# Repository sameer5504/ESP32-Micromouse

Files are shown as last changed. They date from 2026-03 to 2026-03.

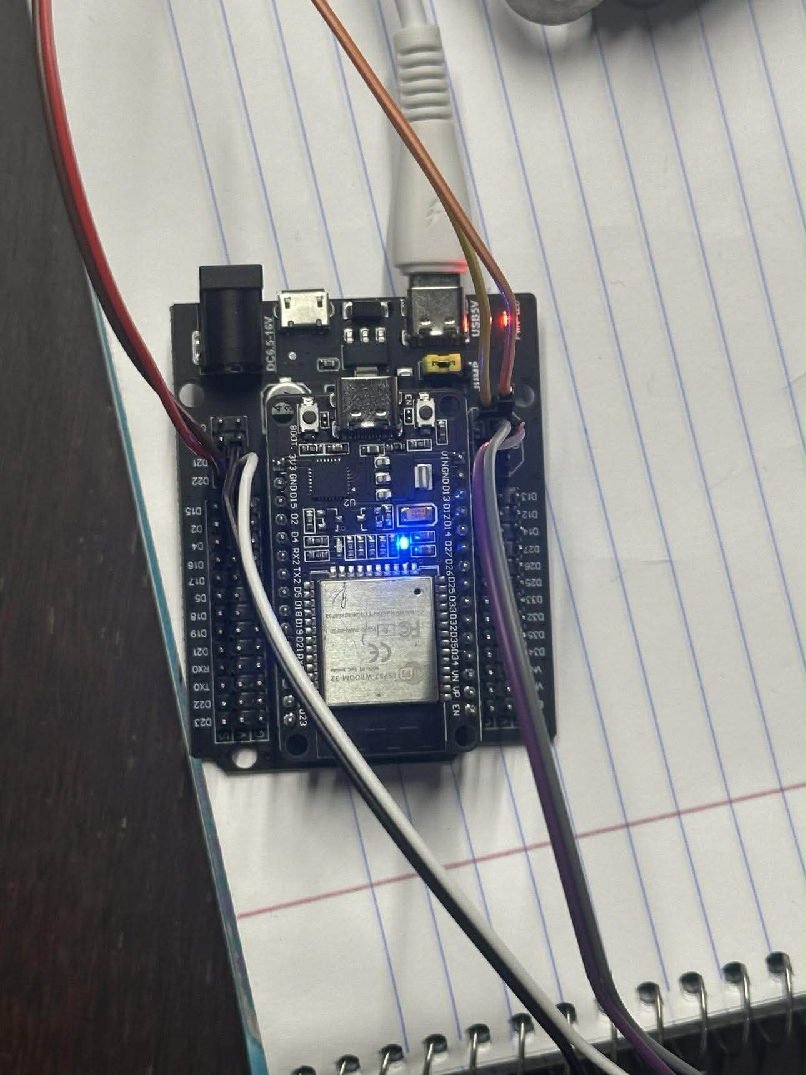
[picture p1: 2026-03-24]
ESP32 Sensor testing.jpg

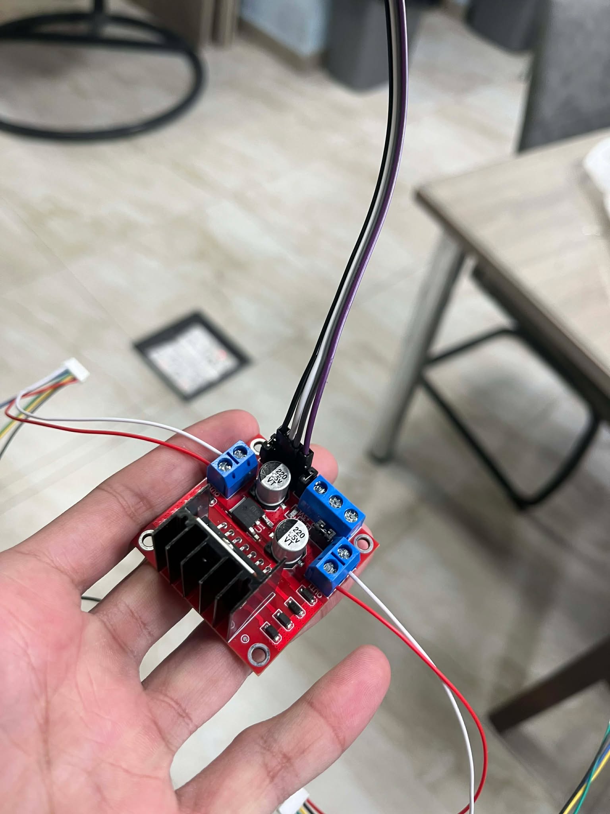
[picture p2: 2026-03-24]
L928N - H bridge.jpg

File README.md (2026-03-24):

# 🐭 ESP32 Micromouse – Flood Fill Maze Solver

## 📌 Overview

This project implements a **Micromouse robot** using an ESP32 microcontroller that autonomously navigates and solves a maze using the **Flood Fill algorithm**.

The robot explores the maze using sensors, builds a map in real time, computes the shortest path to the center, and optimizes its route over multiple runs.

---

## ⚙️ Hardware Components

* ESP32 Microcontroller
* ESP32 30-pin Expansion Board (Shield)
* MPU6050 (Gyroscope + Accelerometer)
* DC Motors with Encoders ×2
* L298N (L928N) H-Bridge Motor Driver
* VL53L0X LiDAR Sensors ×2 (Left & Right)
* IR Sensor (Front wall detection)
* Caster Balls ×2

---

## 🔌 Pin Configuration

| Component | ESP32 Pin |
| --- | --- |
| Motor IN1 | 25 |
| Motor IN2 | 26 |
| Motor IN3 | 27 |
| Motor IN4 | 14 |
| Left Encoder  | 32 |
| Right Encoder | 4 |
| LiDAR XSHUT 1 | 17 |
| LiDAR XSHUT 2 | 18 |
| IR Sensor | 19 |
| I2C SDA | 21 |
| I2C SCL | 22 |

---

## 🧠 Algorithm

### Flood Fill Algorithm

* The maze is represented as an **8×8 grid**
* Each cell stores:

  * Walls (N, E, S, W)
  * Cost (distance to goal)
* The robot:

  1. Explores the maze using sensors
  2. Updates walls dynamically
  3. Recomputes shortest paths using **BFS (Flood Fill)**
  4. Moves toward the lowest-cost neighbor

---

## 🤖 Robot Behavior

### Exploration Phase

* Uses:

  * IR sensor → front wall
  * LiDAR → left/right walls
* Updates maze map in real-time
* Recomputes path continuously

### Optimization Phase

* Once the optimal path is stable:

  * Stops using sensors
  * Runs fastest path

---

## ⚡ Motion Control

* **Yaw correction** using MPU6050
* **PID-like control** for:

  * Straight movement
  * Precise turning
* Encoder-based distance tracking

---

## 📏 Key Parameters

* Wheel diameter: 46 mm
* Cell size: 190 mm
* Encoder resolution: 203 ticks/rev
* Base speed: 50 PWM
* Turn tolerance: ±0.5°

---

## 📂 Code Structure

* **Motor Control** → PWM + direction logic
* **Sensors API** → IR + LiDAR readings
* **IMU Handling** → angle tracking & calibration
* **Flood Fill** → BFS-based pathfinding
* **Stack/Queue** → path tracking & backtracking

---

## 🚀 How It Works

1. Robot starts at (0,0)
2. Moves forward while sensing walls
3. Updates internal maze representation
4. Runs Flood Fill to compute shortest path
5. Reaches center goal
6. Returns to start
7. Repeats until optimal path is found

---

## 📸 Demo

*(Add your video or images here)*

---

## 🛠️ How to Run

1. Open project in Arduino IDE / PlatformIO
2. Install required libraries:

   * Adafruit MPU6050
   * Adafruit VL53L0X
3. Upload code to ESP32
4. Place robot in maze and power on

---

## 📈 Future Improvements

* Faster path optimization
* Better PID tuning
* Diagonal movement
* Map visualization interface

---

## 👨‍💻 Author

**Sameer**
Computer Engineering Student

---

## ⭐ Notes

This project combines:

* Embedded Systems
* Robotics
* Algorithms (Flood Fill / BFS)
* Real-time control

---

> Built as part of a Micromouse robotics project using ESP32 🚀

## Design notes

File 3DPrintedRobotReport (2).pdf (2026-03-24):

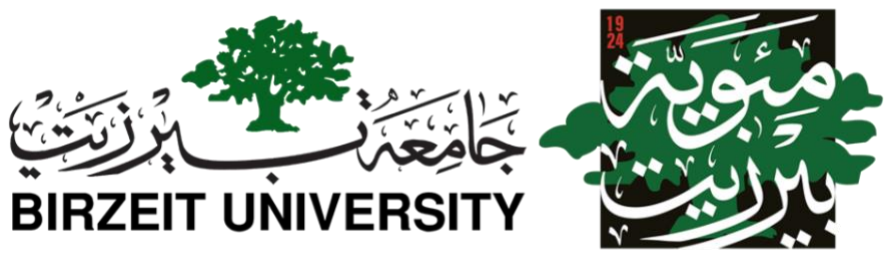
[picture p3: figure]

### Faculty of Engineering & Technology

### Department of Computer Science

### INTERFACING TECHNIQUES ‐ ENCS 4380

### First Semester - 2025/2026

### 3D Printing Homework

Prepared by:

Samir Ali | 1222350
Ibrahim Al Ardah | 1220874
Maen Foqaha | 1220847
Mohammad Ewais | 1220053

Sec. 1 & 2

Instructor: Dr. Wasel Ghanem

Date: 25.10.2025

## Design Objectives

The main objective of this 3D design was to create a compact, lightweight, and durable chassis for a Micromouse robot that could be easily fabricated using 3D printing. The design focuses on achieving a strong structural framework that maintains balance, accessibility, and a clean aesthetic suitable for competition use.

The chassis was developed with the following key goals:

- Ease of Fabrication: Ensure that the entire body can be efficiently produced using standard 3D printing materials with minimal support structures.
- Structural Strength and Stability: Provide a rigid frame capable of withstanding vibrations and small impacts while supporting essential components including motors, sensors, and the battery pack.
- Compact and Balanced Layout: Maintain a symmetrical and low profile design to achieve even weight distribution, enhancing maneuverability and stability during maze navigation.
- Accessibility and Modularity: Integrate mounting holes, open sections, and layered plates that allow easy assembly, disassembly, and maintenance of the robot’s components.
- Aesthetic and Functional Design: Combine clean, modern geometry with smooth edges and cutouts that not only reduce weight but also contribute to a professional and visually appealing appearance.

## Design Approach

The design approach for this Micromouse chassis centered around creating a simple, rigid, and easily manufacturable 3D printed structure that balances practicality, strength, and visual appeal. The robot body was designed with a two-layer configuration connected by sensor-holding side supports, forming a compact and stable frame to hold all main components such as the motors, sensors, control board, and battery pack.

The lower plate is the foundation of the robot, supporting the front mounted sensors and wheels while maintaining sufficient ground clearance to avoid friction during movement. The upper plate provides a mounting space for the battery and microcontroller, keeping heavier components closer to the center to achieve a low and balanced center of gravity essential for accurate and stable navigation within a maze environment. The side walls add rigidity to the chassis while also serving as sensor holders.

From a fabrication standpoint, the design was optimized for 3D printing. The geometry was simplified to include smooth contours, uniform wall thickness, and minimal overhangs, allowing the model to print without the need for excessive support. Mounting holes and slots were incorporated with proper 3D printing tolerances to ensure that sensors, screws, and other hardware could be easily installed after printing.

The open, layered architecture also ensures accessibility and modularity. Each component such as the wheels, motors, and sensors can be installed or removed without disassembling the entire robot. This design choice supports quick maintenance and easy upgrades during the testing phase. Additionally, the top plate includes cutouts and openings for wire routing, ensuring a neat and organized layout.

Aesthetically, the design integrates a clean and modern appearance with smooth curves and uniform alignment between layers. The use of colors and symmetrical structure enhances visibility and gives the Micromouse a professional, finished look for presentation and competition display.

Key design highlights include:

- Two layer chassis structure for stability and easy component separation.
- Centralized layout for balanced weight distribution and low center of gravity.
- Optimized geometry for efficient 3D printing with minimal support.
- Accessible design for fast assembly and maintenance.
- Clean aesthetic emphasizing symmetry.

## Screenshots/3D Rendering of The Robot

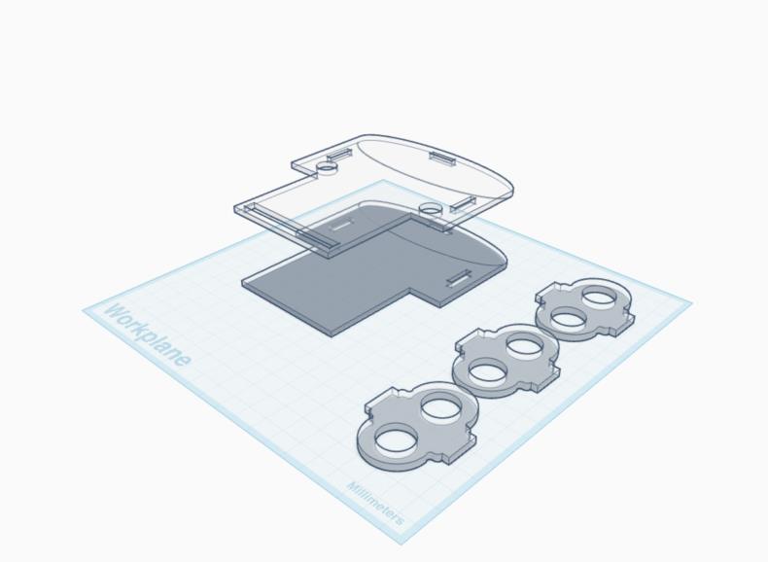
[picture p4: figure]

Figure 1: 3D Printed Base – Perspective View

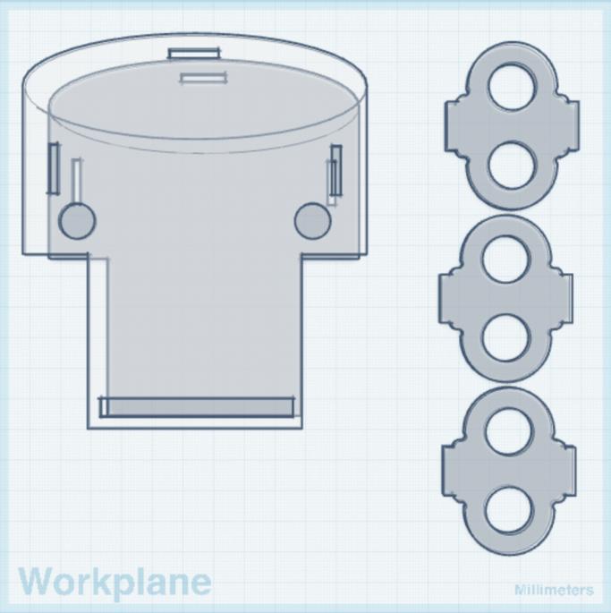
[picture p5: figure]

Figure 2: 3D Printed Base – Flat Top View

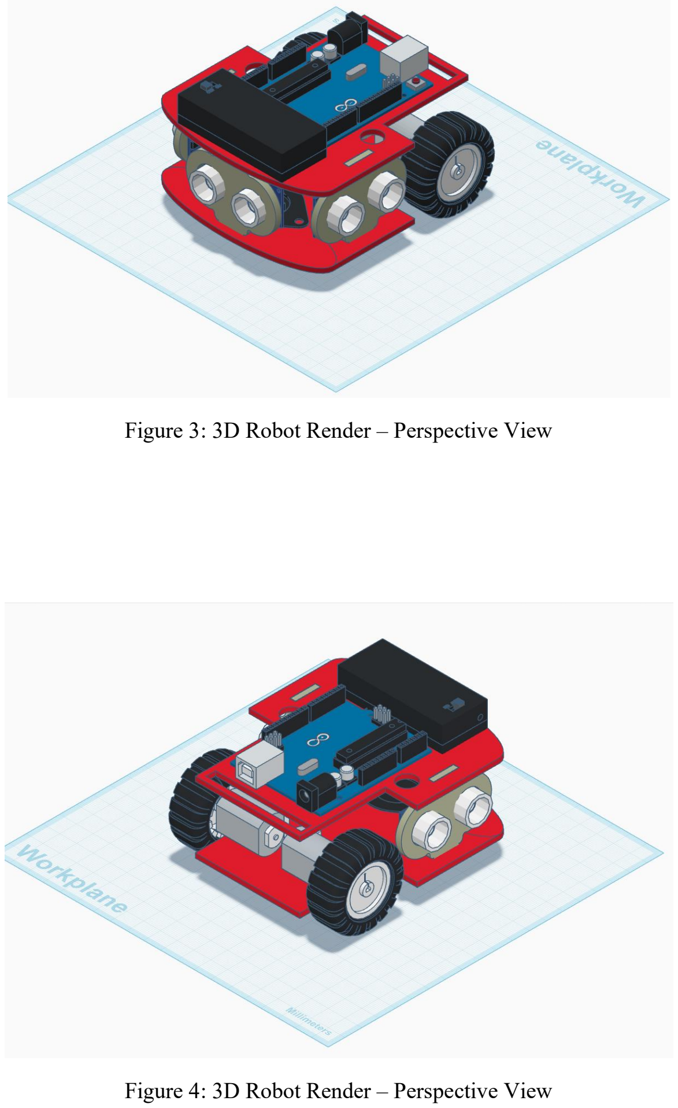
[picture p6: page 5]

Figure 3: 3D Robot Render – Perspective View

Figure 4: 3D Robot Render – Perspective View

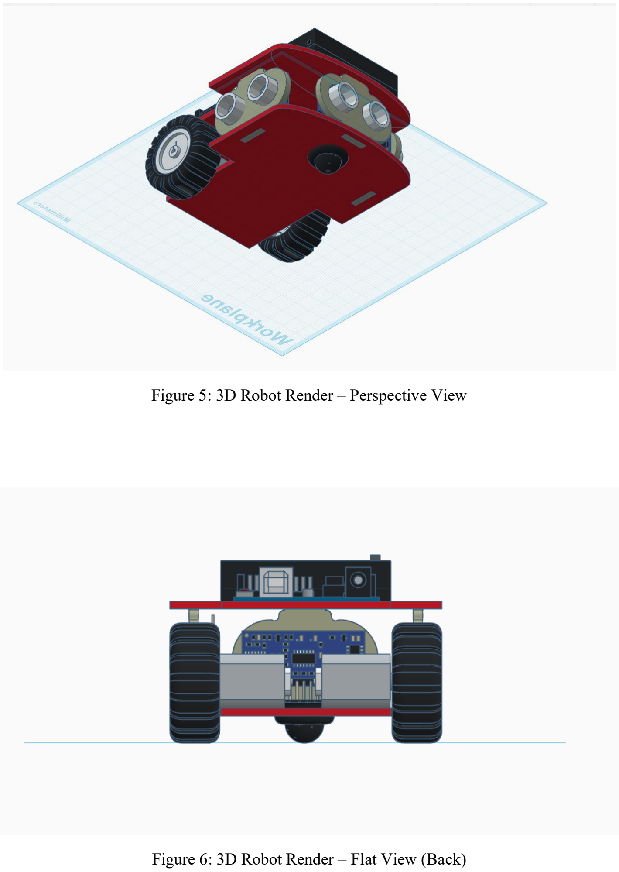
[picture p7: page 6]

Figure 5: 3D Robot Render – Perspective View

Figure 6: 3D Robot Render – Flat View (Back)

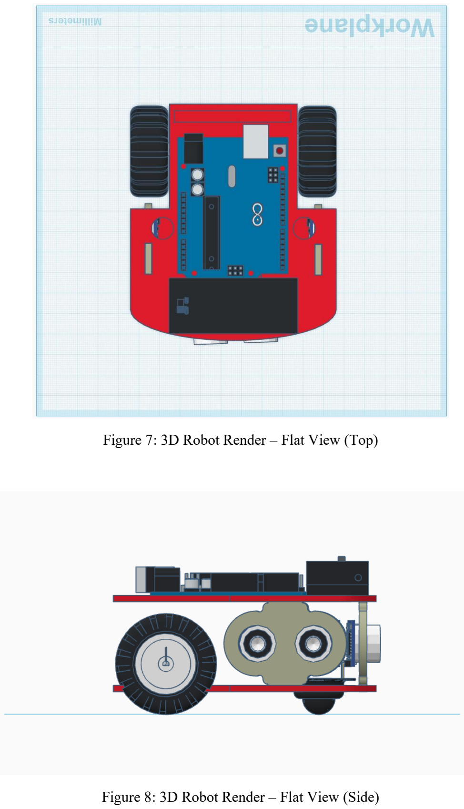
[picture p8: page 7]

Figure 7: 3D Robot Render – Flat View (Top)

Figure 8: 3D Robot Render – Flat View (Side)

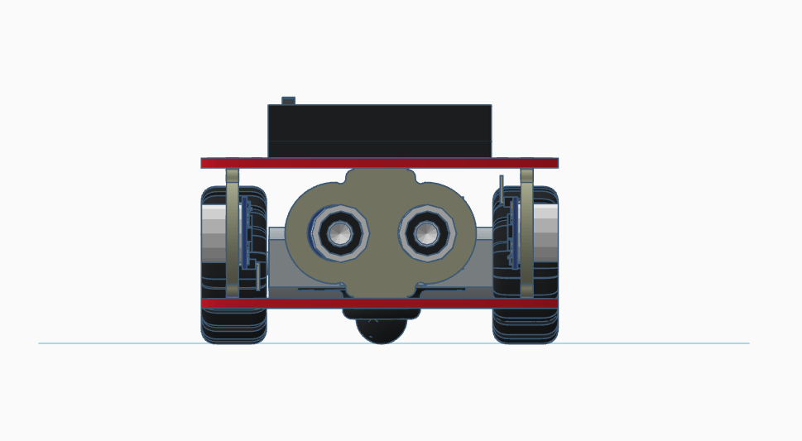
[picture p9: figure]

Figure 9: 3D Robot Render – Flat View (Front)

## Explanation of Chosen design features and their purpose

The design of the Micromouse chassis focuses on achieving a balance between simplicity, structural rigidity, and ease of manufacture through 3D printing. The chassis features a two layer configuration connected by sensor supporting side walls, creating a compact and stable framework capable of securely housing all key components including the motors, sensors, control board, and battery pack.

The lower plate functions as the robot’s structural base, supporting the wheels and front-mounted sensors while maintaining ground clearance to prevent friction during running. The upper plate provides mounting points for the battery and microcontroller, positioning heavier components near the center to maintain a low and balanced center of gravity, which is crucial for precise navigation within a maze. The side supports not only increase the overall rigidity of the chassis but also serve as convenient mounting points for sensors, ensuring consistent alignment and stability.

From a manufacturing perspective, the design is optimized for efficient 3D printing. It features smooth contours, uniform wall thickness, reducing the need for excessive support structures and improving print quality. Predefined mounting holes and slots with appropriate tolerances allow for easy installation of hardware after printing.

The open and modular layout enhances accessibility, enabling individual components such as motors, wheels, and sensors to be installed or replaced without dismantling the entire assembly. This modularity facilitates quick maintenance and upgrades during testing. Additionally, cutouts on the top plate provide clear pathways for cable management, resulting in a tidy and organized internal layout.

Aesthetically, the chassis presents a clean, modern appearance with smooth curves and a symmetrical form. The use of bright, contrasting colors improves visibility and gives the Micromouse a polished, professional look suitable for competition and display.

Key design features and their purposes include:

- Two layer chassis: Enhances structural stability and simplifies component organization.
- Centralized component layout: Promotes balanced weight distribution and a low center of gravity.
- 3D printing optimization: Ensures easy, reliable fabrication with minimal support material.
- Modular accessibility: Simplifies assembly, maintenance, and component replacement.
- Refined aesthetics: Provides visual appeal through symmetry and clean design lines.

## Summary of Tools and Methods Used

The design of the Micromouse chassis was developed using Tinker cad, a 3D modeling software for prototyping and design projects. Tinker cad's user interface and block based modeling tools allowed for precise control over dimensions, alignment, and component placement. The design process involved creating individual parts such as the upper and lower plates, side supports, and sensor mounts, which were then assembled virtually to evaluate fit and functionality. The software’s perspective features enabled easy inspection of the chassis from multiple angles, ensuring proper spacing for components and efficient weight distribution. Once the final design was completed, the model was exported to STL format for 3D printing. This workflow allowed for efficient iteration, quick modifications, and accurate translation of the digital design into a physical prototype.

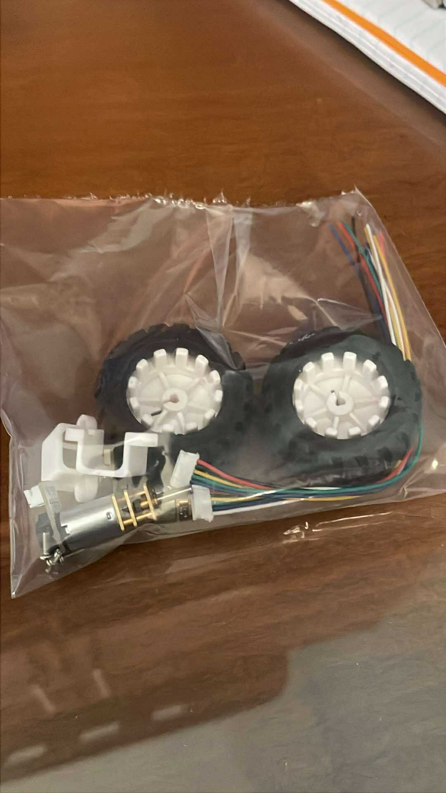
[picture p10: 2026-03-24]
DC motors with encoders.jpg

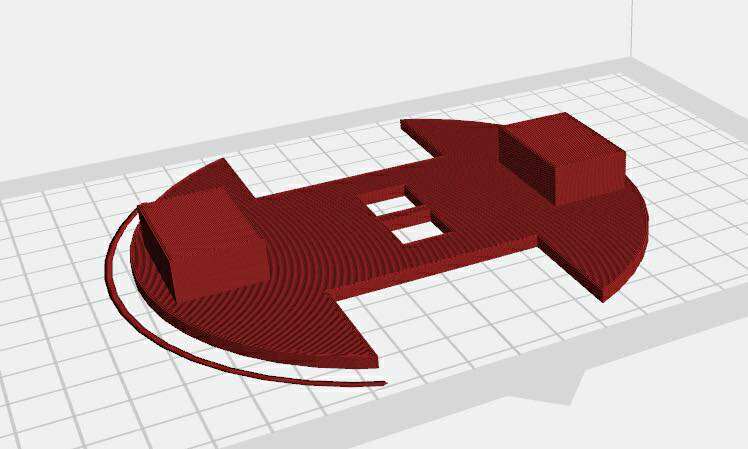
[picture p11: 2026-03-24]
Bottom Base.jpg

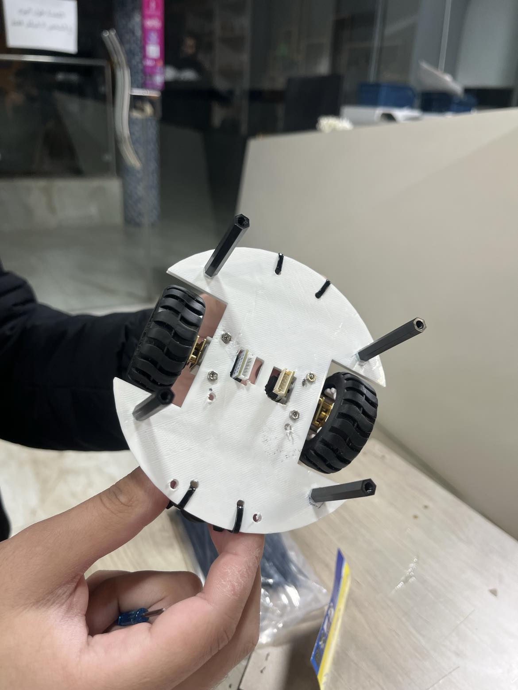
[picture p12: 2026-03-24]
DC motors with encoder fitment_.jpg

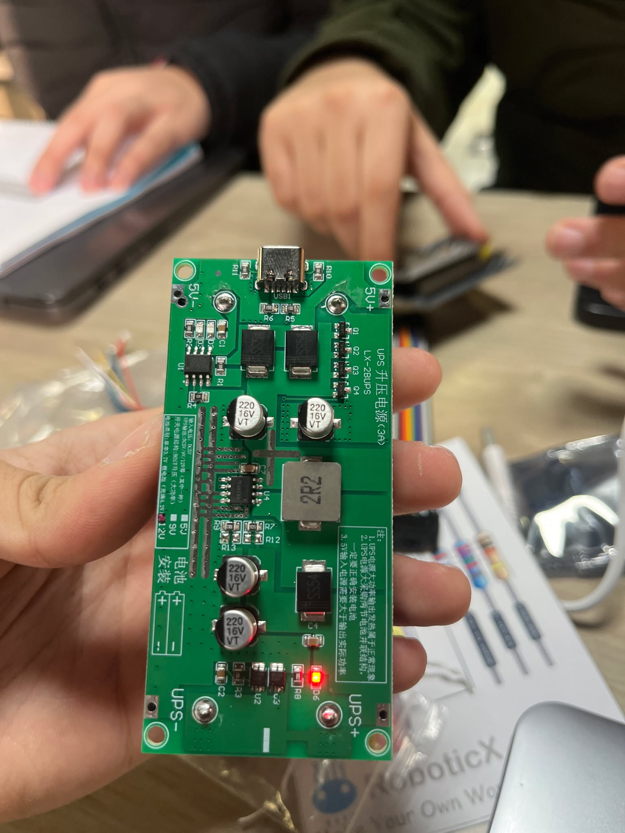
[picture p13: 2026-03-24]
Battery base.jpg

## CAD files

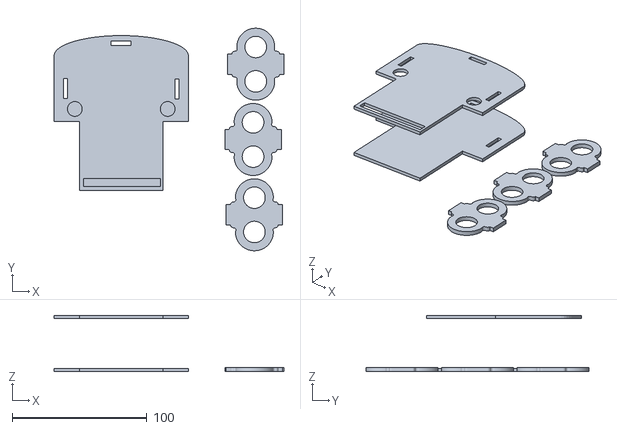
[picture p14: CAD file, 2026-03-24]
Initial design.stl
171.0 x 165.5 x 42.0

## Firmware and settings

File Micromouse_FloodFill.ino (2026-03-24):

// === Libraries and Definitions ===
#include <Wire.h>
#include <Adafruit_MPU6050.h>
#include <Adafruit_Sensor.h>
#include <Adafruit_VL53L0X.h>
#include <stdio.h>
#include <stdlib.h>
#include <string.h>
#include <Arduino.h>

// Pins
// Motor Pins
#define IN1 25
#define IN2 26
#define IN3 27
#define IN4 14
// Encoder Pins
#define L_ENC 32
#define R_ENC 4
// LiDAR Pins and IR Pins
#define SHT_LOX1 17
#define SHT_LOX2 18
#define LOX1_ADDRESS 0x30
#define LOX2_ADDRESS 0x31
#define IR_FRONT 19
#define MAX_MAZE 8 // max maze

// Tuning Constants
const float wheel_d = 46.0;  // Wheel Diameter (mm)
const float wheel_c = PI * wheel_d;  // Wheel Circumference (mm)
const int counts_per_rev = 203;  // Encoder ticks per rev
const int cell_size = 190;  // Cell size (mm)
const int BASE_SPEED = 50;  // Forward Movement Speed (0-255)
const int MIN_DRIVE_PWM = 40;  // Minimum Forward Movement Speed
const int TURN_BASE_SPEED = 50;  // Turn Speed (0-255)
const int MIN_TURN_PWM = 24;  // Minimum Turn Speed
const float KP_YAW = 2.0;
const float TURN_KP = 1.5;
const float TURN_TOLERANCE = 0.5;  // Tolerance for angle when using MPU
const long CELL_TICKS = (long)round((cell_size / wheel_c) * counts_per_rev);  // Ticks Per Cell

// Global Variables
volatile long leftTicks = 0;
volatile long rightTicks = 0;
Adafruit_MPU6050 mpu;
float currentAngle = 0;
float gyroZ_bias = 0;
unsigned long lastTime;

// Structs for Flood Fill
//Stack
typedef struct stack_node *ptrS;
struct stack_node{
    int wantedDir;
    ptrS next;
};
typedef ptrS Stack;
//Queue
typedef struct queue_node *ptrQN;
struct queue_node{
    int x, y;
    ptrQN next;
};
typedef ptrQN QNode;
typedef struct empty_queue *Queue;
struct empty_queue{
    ptrQN front;
    ptrQN rear;
};
//Stack Functions
static Stack stackPush(Stack s, int wantedDir){
    ptrS n = (ptrS)malloc(sizeof(*n));
    n->wantedDir = wantedDir;
    n->next = s;
    return n;
}
static int stackIsEmpty(Stack s){ return s==NULL; }
static int stackPop(Stack* ps){
    if(!*ps) return -1;
    ptrS t = *ps;
    int d = t->wantedDir;
    *ps = t->next;
    free(t);
    return d;
}
// Queue Functions
static Queue makeQueue(){
    Queue q = (Queue)malloc(sizeof(*q));
    q->front = q->rear = NULL;
    return q;
}
static int queueEmpty(Queue q){ return q->front==NULL; }
static void enqueue(Queue q, int x, int y){
    QNode n = (QNode)malloc(sizeof(*n));
    n->x = x; n->y = y; n->next = NULL;
    if(q->rear) q->rear->next = n; else q->front = n;
    q->rear = n;
}
static int dequeue(Queue q, int* x, int* y){
    if(!q->front) return 0;
    QNode n = q->front;
    *x = n->x; *y = n->y;
    q->front = n->next;
    if(!q->front) q->rear = NULL;
    free(n);
    return 1;
}
static int stackPeek(Stack s){
    if(!s) return -1;
    return s->wantedDir;
}
// Motor and Encoders
void IRAM_ATTR leftISR(){
    leftTicks++;
}

void IRAM_ATTR rightISR(){
    rightTicks++;
}

void writePWMtoPin(int pin, int value) {
    analogWrite(pin, value);
}

void setMotor(int left, int right) {
    left = constrain(left, -255, 255);
    right = constrain(right, -255, 255);
    // Left
    if(left > 0){
        writePWMtoPin(IN1, 0);
        writePWMtoPin(IN2, left);
    } else {
        writePWMtoPin(IN1, -left);
        writePWMtoPin(IN2, 0);
    }
    // Right
    if(right > 0){
        writePWMtoPin(IN3, right);
        writePWMtoPin(IN4, 0);
    } else {
        writePWMtoPin(IN3, 0);
        writePWMtoPin(IN4, -right);
    }
}

void stopMotors() {
    writePWMtoPin(IN1,0);
    writePWMtoPin(IN2,0);
    writePWMtoPin(IN3,0);
    writePWMtoPin(IN4,0);
}

// MPU
void calibrateGyro() {
    delay(1000);
    float sum = 0;
    const int samples = 600;
    for(int i=0;i<samples;i++){
        sensors_event_t a,g,t;
        mpu.getEvent(&a,&g,&t);
        sum += g.gyro.z;
        delay(2);
    }
    gyroZ_bias = sum / (float)samples;
}

void updateAngle() {
    sensors_event_t a,g,t;
    mpu.getEvent(&a,&g,&t);
    unsigned long now = micros();
    float dt = (now - lastTime) / 1000000.0f;
    if (dt > 0.05f) dt = 0.05f;  // clamp large jumps
    lastTime = now;
    float gyroZ = (g.gyro.z - gyroZ_bias) * 57.29577951308232f; // rad/s -> deg/s
    currentAngle += gyroZ * dt;
}

float angleError(float target, float current) {
    return target - current;
}
// Sensors (Lidar + IR)
Adafruit_VL53L0X loxLeft = Adafruit_VL53L0X();
Adafruit_VL53L0X loxRight = Adafruit_VL53L0X();
VL53L0X_RangingMeasurementData_t measureLeft;
VL53L0X_RangingMeasurementData_t measureRight;
void setupLIDAR() {
    pinMode(SHT_LOX1, OUTPUT);
    pinMode(SHT_LOX2, OUTPUT);
    digitalWrite(SHT_LOX1, LOW);
    digitalWrite(SHT_LOX2, LOW);
    delay(10);
    digitalWrite(SHT_LOX1, HIGH);
    loxRight.begin(LOX1_ADDRESS);
    digitalWrite(SHT_LOX2, HIGH);
    loxLeft.begin(LOX2_ADDRESS);
}

// === API Functions ===
bool API_wallFront() {
    int v = digitalRead(IR_FRONT);
    return (v == LOW);
}

bool API_wallLeft() {
    loxLeft.rangingTest(&measureLeft, false);
    return (measureLeft.RangeMilliMeter - 43) <= 150;
}

bool API_wallRight() {
    loxRight.rangingTest(&measureRight, false);
    return (measureRight.RangeMilliMeter - 43) <= 150;
}

bool API_moveForward() {
    leftTicks = 0; rightTicks = 0;
    float targetYaw = currentAngle;
    lastTime = micros();
    while( (leftTicks + rightTicks) / 2 < CELL_TICKS ) {
        updateAngle();
        float error = currentAngle - targetYaw;
        float corr = KP_YAW * error;
        int leftSpeed = (int)round(BASE_SPEED - corr);
        int rightSpeed = (int)round(BASE_SPEED + corr);
        if(abs(leftSpeed) < MIN_DRIVE_PWM){
            if(leftSpeed >= 0){
                leftSpeed = MIN_DRIVE_PWM;
            }else{
                leftSpeed = -MIN_DRIVE_PWM;
            }
        }
        if (abs(rightSpeed) < MIN_DRIVE_PWM) {
            if (rightSpeed >= 0) {
                rightSpeed = MIN_DRIVE_PWM;
            } else {
                rightSpeed = -MIN_DRIVE_PWM;
            }
        }
        setMotor(leftSpeed, rightSpeed);
    }
    stopMotors();
    delay(120);
    return true;
}

void API_turnRight() {
    float start = currentAngle;
    float target = start + 81.5f;
    lastTime = micros();
    while (fabs(angleError(target, currentAngle)) > TURN_TOLERANCE) {
        updateAngle();
        float err = angleError(target, currentAngle);
        int pwm = (int)round(fabs(err) * TURN_KP);
        pwm = constrain(pwm, MIN_TURN_PWM, TURN_BASE_SPEED);
        if (err > 0) {
            setMotor(pwm, -pwm); // Turn Right
        } else {
            setMotor(-pwm, pwm); // Reverse to target
        }
    }
    stopMotors();
    delay(40);
    int brakePwm = MIN_TURN_PWM;
    setMotor(-brakePwm, brakePwm);
    delay(60);
    stopMotors();
    delay(80);
}

void API_turnLeft() {
    float start = currentAngle;
    float target = start - 82.0f;
    lastTime = micros();
    while (fabs(angleError(target, currentAngle)) > TURN_TOLERANCE) {
        updateAngle();
        float err = angleError(target, currentAngle);
        int pwm = (int)round(fabs(err) * TURN_KP);
        pwm = constrain(pwm, MIN_TURN_PWM, TURN_BASE_SPEED);
        if (err < 0) {
            setMotor(-pwm, pwm); // Turn Left
        } else {
            setMotor(pwm, -pwm); // Reverse to correct overshoot
        }
    }
    stopMotors();
    delay(40);
    int brakePwm = MIN_TURN_PWM;
    setMotor(brakePwm, -brakePwm);
    delay(60);
    stopMotors();
    delay(80);
}
// === Flood Fill ===
static void log_text(const char* text) {
    Serial.print(text);
}
//----------DIRECTIONS-----------
// 0 = North (+Y), 1 = East (+X), 2 = South (-Y), 3 = West (-X)
static const int dx[4]     = { 0,  1,  0, -1 };
static const int dy[4]     = { 1,  0, -1,  0 };
static const int revdir[4] = { 2,  3,  0,  1 };
static const char* dirChar[4] = {"North","East","South","West"};

//-----------Rotation------------
static void rotateRight(int* h){
    API_turnRight();
    *h = (*h + 1) & 3;
}
static void rotateLeft(int* h){
    API_turnLeft();
    *h = (*h + 3) & 3;
}
static void rotateTo(int target, int* h) {
    if (target < 0 || target > 3) return;
    int diff = (target - *h + 4) & 3;
    if (diff == 0) return;
    else if (diff == 1) rotateRight(h);
    else if (diff == 2) { rotateRight(h); rotateRight(h); }
    else if (diff == 3) rotateLeft(h);
}
//----------Heuristics-----------
void manhattanToNearestCenter(int W,int H,int x,int y){
    int x1 = W/2;
    int	x2 = x1-1;
    int y1 = H/2;
    int	y2 = y1-1;
    int c1 = abs(x - x1) + abs(y - y1);
    int c2 = abs(x - x1) + abs(y - y2);
    int c3 = abs(x - x2) + abs(y - y1);
    int c4 = abs(x - x2) + abs(y - y2);
    int min = c1;
    if(c2 < min) min = c2;
    if(c3 < min) min = c3;
    if(c4 < min) min = c4;
    char str[16];
    sprintf(str, "%d", min);
}
//------ Sensing the walls ------
// Sensor mapping: front -> heading
// left  -> (heading + 3) & 3 (counter-clockwise)
// right -> (heading + 1) & 3 (clockwise)

static void senseAndUpdateWalls(int W,int H,int x,int y,int heading, unsigned char walls[MAX_MAZE][MAX_MAZE][4]){
    int front = API_wallFront() ? 1 : 0;
    int left  = API_wallLeft()  ? 1 : 0;
    int right = API_wallRight() ? 1 : 0;
    int dirFront = heading & 3;
    int dirLeft  = (heading + 3) & 3; // left is ccw
    int dirRight = (heading + 1) & 3; // right is cw
    walls[y][x][dirFront] = front;
    walls[y][x][dirLeft]  = left;
    walls[y][x][dirRight] = right;

    // Boundaries are walls
    for(int d=0; d<4; ++d){
        int nx = x + dx[d], ny = y + dy[d];
        if(nx < 0 || ny < 0 || nx >= W || ny >= H) walls[y][x][d] = 1;
    }

    // Mirror walls into neighbors
    for(int d=0; d<4; ++d){
        int nx = x + dx[d], ny = y + dy[d];
        if(nx < 0 || ny < 0 || nx >= W || ny >= H) continue;
        walls[ny][nx][revdir[d]] = walls[y][x][d];
    }
}
//----GLOBAL FLOOD-FILL (BFS)----
// Recompute exact shortest distances from all center goal cells using known walls.
static void recomputeFlood(int W,int H,int cost[MAX_MAZE][MAX_MAZE], unsigned char walls[MAX_MAZE][MAX_MAZE][4]){
    const int INF = 1<<28;
    for(int yy=0; yy<H; ++yy) for(int xx=0; xx<W; ++xx) cost[yy][xx] = INF;

    // center cells (goal) - set to 0 and enqueue
    int gx1 = W/2, gx2 = gx1 - 1;
    int gy1 = H/2, gy2 = gy1 - 1;
    int qx[MAX_MAZE * MAX_MAZE], qy[MAX_MAZE * MAX_MAZE];
    int head = 0, tail = 0;

    if(gx1>=0 && gx1<W && gy1>=0 && gy1<H){
        cost[gy1][gx1] = 0;
        qx[tail]=gx1;
        qy[tail]=gy1;
        tail++;
    }
    if(gx1>=0 && gx1<W && gy2>=0 && gy2<H){
        if(cost[gy2][gx1] > 0){
            cost[gy2][gx1] = 0;
            qx[tail]=gx1;
            qy[tail]=gy2;
            tail++;
        }
    }
    if(gx2>=0 && gx2<W && gy1>=0 && gy1<H){
        if(cost[gy1][gx2] > 0){
            cost[gy1][gx2] = 0;
            qx[tail]=gx2;
            qy[tail]=gy1;
            tail++;
        }
    }
    if(gx2>=0 && gx2<W && gy2>=0 && gy2<H){
        if(cost[gy2][gx2] > 0){
            cost[gy2][gx2] = 0;
            qx[tail]=gx2;
            qy[tail]=gy2;
            tail++;
        }
    }

    while(head < tail){
        int cx = qx[head], cy = qy[head];
        head++;
        int base = cost[cy][cx];
        for(int d=0; d<4; ++d){
            if(walls[cy][cx][d]) continue;
            int nx = cx + dx[d], ny = cy + dy[d];
            if(nx < 0 || ny < 0 || nx >= W || ny >= H) continue;
            if(cost[ny][nx] > base + 1){
                cost[ny][nx] = base + 1;
                qx[tail] = nx; qy[tail] = ny; tail++;
            }
        }
    }

    // update text display
    for(int yy=0; yy<H; ++yy){
        for(int xx=0; xx<W; ++xx){
            char buf[8];
            if(cost[yy][xx] < INF) sprintf(buf, "%d", cost[yy][xx]);
            else sprintf(buf, "X");
        }
    }
}

void setup() {
    Serial.begin(115200);
    pinMode(IN1,OUTPUT);
    pinMode(IN2,OUTPUT);
    pinMode(IN3,OUTPUT);
    pinMode(IN4,OUTPUT);
    pinMode(L_ENC, INPUT_PULLUP);
    pinMode(R_ENC, INPUT_PULLUP);
    attachInterrupt(digitalPinToInterrupt(L_ENC), leftISR, RISING);
    attachInterrupt(digitalPinToInterrupt(R_ENC), rightISR, RISING);
    setupLIDAR();
    Wire.begin(21,22);
    if(!mpu.begin()){
        Serial.println("MPU6050 not found!");
        while(1);
    }
    calibrateGyro();
    lastTime = micros();
    Serial.println("READY");
}

void loop() {
    log_text("Running Using Flood Fill Algorithm...");
    delay(1000);
    Serial.print("1.");
    delay(1000);
    Serial.print("2.");
    delay(1000);
    Serial.print("3.");
    // Calculate Goal Coordinates
    const int W = 8;
    const int H = 8;
    int gx1 = W/2;
    int	gx2 = gx1 - 1;
    int gy1 = H/2;
    int	gy2 = gy1 - 1;
    static int cost[MAX_MAZE][MAX_MAZE];
    static unsigned char walls[MAX_MAZE][MAX_MAZE][4]; // 1=blocked, 0=open
    static unsigned char visited[MAX_MAZE][MAX_MAZE];
    for(int yy=0; yy<H; ++yy){  // Calculate Manhattan Distance for all cells
        for(int xx=0; xx<W; ++xx){
            visited[yy][xx] = 0;
            for(int d=0; d<4; ++d) {
                walls[yy][xx][d] = 0;
            }
            manhattanToNearestCenter(W,H,xx,yy);
        }
    }

    // Set Maze borders as walls
    for(int xx=0; xx<W; ++xx){
        walls[0][xx][2] = 1;
        walls[H-1][xx][0] = 1;
    }
    for(int yy=0; yy<H; ++yy){
        walls[yy][0][3] = 1;
        walls[yy][W-1][1] = 1;
    }

    int x = 0; // Start at 0,0 and heading in direction 0 (North)
    int y = 0;
    int heading = 0;
    Stack path = NULL;

    // For detecting the final path
    int path_signature_x = 0;
    int path_signature_y = 0;
    int previous_path_signature_x=0;
    int previous_path_signature_y=0;
    int final_path_found = 0;
    recomputeFlood(W,H,cost,walls);
    int i=1;
    int i2=1;

    while(1){ // Keeps running, so minimum run time can be used as the official run time
        previous_path_signature_x = path_signature_x;
        previous_path_signature_y = path_signature_y;
        path_signature_x = 0;
        path_signature_y = 0;
        char strLog[50];
        if (final_path_found==0){
            sprintf(strLog, "=== RUN #%d USING SENSORS ===", i);
            Serial.println(strLog);			i++;
        }else {
            sprintf(strLog, "=== RUN #%d WITHOUT SENSORS ===", i2);
            Serial.println(strLog);			i2++;
        }
        log_text(strLog);

        while(!( (x==gx1&&y==gy1) || (x==gx1&&y==gy2) || (x==gx2&&y==gy1) || (x==gx2&&y==gy2) )){ // Until reaching the goal
            path_signature_x = path_signature_x + x;
            path_signature_y = path_signature_y + y;
            visited[y][x] = 1;

            if (final_path_found==0){  // Use Sensors and Flood Fill Algorithm
                // sense and update walls based on sensors relative to heading
                senseAndUpdateWalls(W,H,x,y,heading,walls);
                // recompute full flood after any new wall info
                recomputeFlood(W,H,cost,walls);
                // choose neighbor with lowest cost
            }
            int bestDir = -1;
            int here = cost[y][x];
            int bestCost = here;
            for(int d=0; d<4; ++d){
                if(walls[y][x][d]) continue;
                int nx = x + dx[d];
                int ny = y + dy[d];
                if(nx < 0 || ny < 0 || nx >= W || ny >= H) continue;
                if(cost[ny][nx] < bestCost){
                    bestCost = cost[ny][nx];
                    bestDir = d;
                }
            }

            int direction_if_backtracking = stackPeek(path);
            if (direction_if_backtracking >= 0 && bestDir == direction_if_backtracking) {
                stackPop(&path);
                rotateTo(direction_if_backtracking, &heading);
                x += dx[direction_if_backtracking];
                y += dy[direction_if_backtracking];
                char buf[128];
                sprintf(buf, "Backtracked to (%d,%d) heading %s", x, y, dirChar[heading]);
                log_text(buf);
                API_moveForward();
            }
            else {
                // go to bestDir
                rotateTo(bestDir, &heading);
                if(!API_moveForward()){
                    // unexpected blocked
                    walls[y][x][bestDir] = 1;
                    int nx = x + dx[bestDir], ny = y + dy[bestDir];
                    if(nx >= 0 && ny >= 0 && nx < W && ny < H) walls[ny][nx][revdir[bestDir]] = 1;
                    recomputeFlood(W,H,cost,walls);
                } else {
                    // push reverse direction for backtrack
                    path = stackPush(path, revdir[bestDir]);
                    x += dx[bestDir]; y += dy[bestDir];
                    char buf[128]; sprintf(buf, "Moved to (%d,%d) heading %s", x, y, dirChar[heading]); log_text(buf);
                }
            }
        }
        if(( (x==gx1&&y==gy1) || (x==gx1&&y==gy2) || (x==gx2&&y==gy1) || (x==gx2&&y==gy2) )) {
            log_text("Goal Reached ! Returning to START using stack...");
            // Pop directions and walk back to the start
            while(!stackIsEmpty(path)) {
                int want = stackPop(&path);       // this is an absolute dir (0..3) to move next
                rotateTo(want, &heading);         // face that direction from current heading
                x += dx[want];
                y += dy[want];
                char buf[128];
                sprintf(buf, "Returning: moved to (%d,%d) heading %s", x, y, dirChar[heading]);
                log_text(buf);
            }
            if(x==0 && y==0) {
                log_text("Back at START. Run complete.");
                if ((path_signature_x == previous_path_signature_x) && (previous_path_signature_y==path_signature_y && final_path_found == 0)){
                    log_text("Final Path Found");
                    final_path_found = 1;
                }
            } else {
                log_text("Error - Did not reach START.");
            }
        }
    }
}

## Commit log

2026-03-24 Initial commit - ESP32 Micromouse
2026-03-24 Create ESP32 Micromouse Connections
2026-03-24 Add files via upload
    The built Micromouse was tested using an IR Sensor, the IR Sensor detects objects in front of the Micromouse, when an object is detected the Micromouse turns until there is no more objects detected i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
2026-03-24 Rename videos to videos of ATMega238P & Arduino Tasks (not directly related to project)
2026-03-24 Rename BaseDesign (1).stl to Initial design.stl
    [Initial design.stl]
